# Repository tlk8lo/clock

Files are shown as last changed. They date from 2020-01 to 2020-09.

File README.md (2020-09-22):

# Timer

A school timer which displays time to the end of lesson/break. Uses [DCF77](https://en.wikipedia.org/wiki/DCF77) time signal for synchronization. Can also work as a typical digital clock. Since this is a project for our school, the documentation is written in Polish.

Szkolny timer wyświetlający czas do końca lekcji/przerwy. Używa sygnału radiowego [DCF77](https://en.wikipedia.org/wiki/DCF77) do synchronizacji czasu. Może również pracować jako normalny zegar cyfrowy.

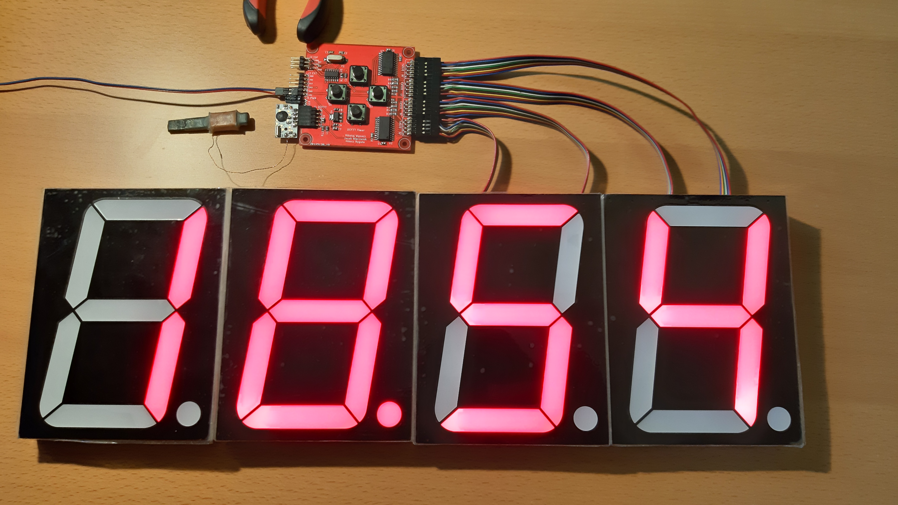
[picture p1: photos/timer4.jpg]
Timer


## Budowa

Urządzenie składa się z mikrokontrolera AVR ATtiny24A, modułu odbiornika sygnału DCF77 oraz 2 układów SCT2024 sterujących 4 dużymi wyświetlaczami 7-segmentowymi. Posiada 4 przyciski do konfiguracji godzin lekcyjnych (zapisywanych w pamięci EEPROM). Wymaga zasilania prądem stałym o napięciu **15V** i pobiera maksymalnie **1,2A**. _Podczas montażu urządzenia, przewód zasilający należy poprowadzić jak najdalej od anteny, ponieważ powoduje on znaczne zakłócenia._

## Sposób działania

Po włączeniu zasilania, urządzenie czeka na odebranie poprawnej ramki DCF77 w celu synchronizacji czasu. Po udanej synchronizacji, wyświetla:

* Aktualną godzinę (jeżeli nie są zapisane żadne lekcje)
* Czas do końca przerwy (jeżeli trwa przerwa)
* Czas do końca lekcji (jeżeli trwa lekcja) - zapala się wtedy kropka po prawej stronie 4 cyfry

Kropka pomiędzy 2 i 3 cyfrą informuje o statusie synchronizacji:

* Jeżeli odebrano poprawną ramkę DCF77 w ciągu ostatnich 24 godzin - kropka świeci się
* W przeciwnym razie - kropka odzwierciedla stan odbiornika DCF77 (pozwala to wizualnie ocenić jakość odbieranego sygnału)

## Konfiguracja lekcji

W celu konfiguracji godzin lekcyjnych, należy nacisnąć dowolny przycisk, aby wejść do menu głównego.\
W menu, poszczególne przyciski umożliwiają nawigację, na zasadzie strzałek:

```
  ↑  
←   →
  ↓  
```

**Menu główne**

W menu głównym można ustawić godziny rozpoczęcia i zakończenia poszczególnych lekcji, a także dodawać i usuwać lekcje.\
Można dodać maksymalnie 32 lekcje.\
Jeżeli usunie się wszystkie lekcje, urządzenie działa jak zwyczajny zegar.

_Na poniższym przykładzie dodano 9 lekcji (od 00 do 08)._

```
                  ------------ Ustaw początek lekcji ------------         Dodaj nową lekcję          
                  ↑                 ↑                           ↑                 ↑                  
             ┌─────────┐       ┌─────────┐                 ┌─────────┐       ┌─────────┐             
Wyjdź    ←   │ 0 0   L │   ↔   │ 0 1   L │   ↔   ...   ↔   │ 0 8   L │   ↔   │ L A S T │   →   Wyjdź 
z menu       └─────────┘       └─────────┘                 └─────────┘       └─────────┘       z menu
                  ↓                 ↓                           ↓                 ↓                  
                  ------------- Ustaw koniec lekcji -------------        Usuń ostatnią lekcję        
```

**Menu ustawiania początku/końca lekcji**

To menu umożliwia zmianę godziny początku/końca danej lekcji.\
Kropka oznacza aktualnie edytowaną cyfrę.\
Domyślnie lekcja trwa 45 min, dlatego koniec lekcji jest ustawiany automatycznie. (Koniec lekcji można nadpisać ręcznie, wybierając "Ustaw koniec lekcji" w menu głównym.)

_Na poniższym przykładzie ustawiono godzinę 09:45._

```
               +                   +                   +                   +               
               ↑                   ↑                   ↑                   ↑               
             ┌─────────┐       ┌─────────┐       ┌─────────┐       ┌─────────┐             
Wróć do  ←   │ 0.9 4 5 │   ↔   │ 0 9.4 5 │   ↔   │ 0 9 4.5 │   ↔   │ 0 9 4 5.│   →  Wróć do
menu gł      └─────────┘       └─────────┘       └─────────┘       └─────────┘      menu gł
               ↓                   ↓                   ↓                   ↓               
               -                   -                   -                   -               
```

## Struktura repozytorium

* [src](src) - kod źródłowy programu mikrokontrolera
* [pcb](pcb) - schemat obwodu i projekt płytki PCB
* [cad](cad) - modele elementów obudowy
* [photos](photos) - zdjęcia gotowego urządzenia

## Licencja

[MIT](LICENSE)

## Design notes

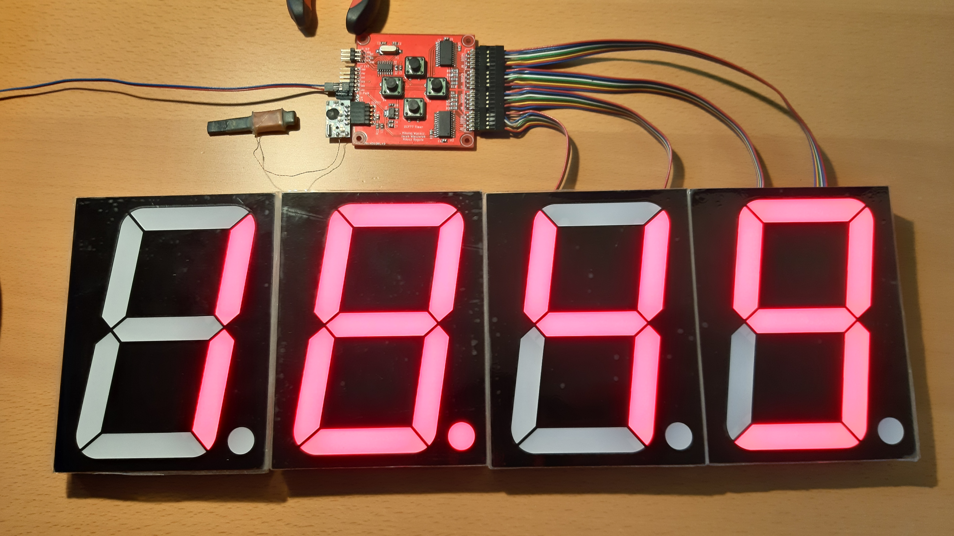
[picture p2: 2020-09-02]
photos/timer3.jpg

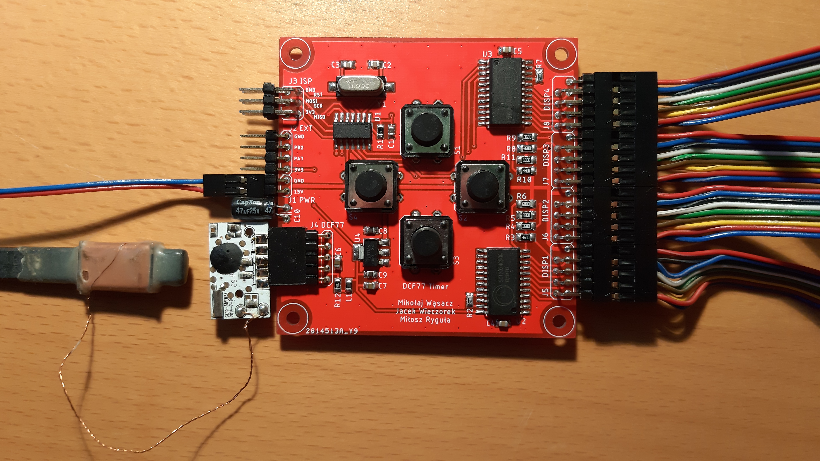
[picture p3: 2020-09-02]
photos/timer1.jpg

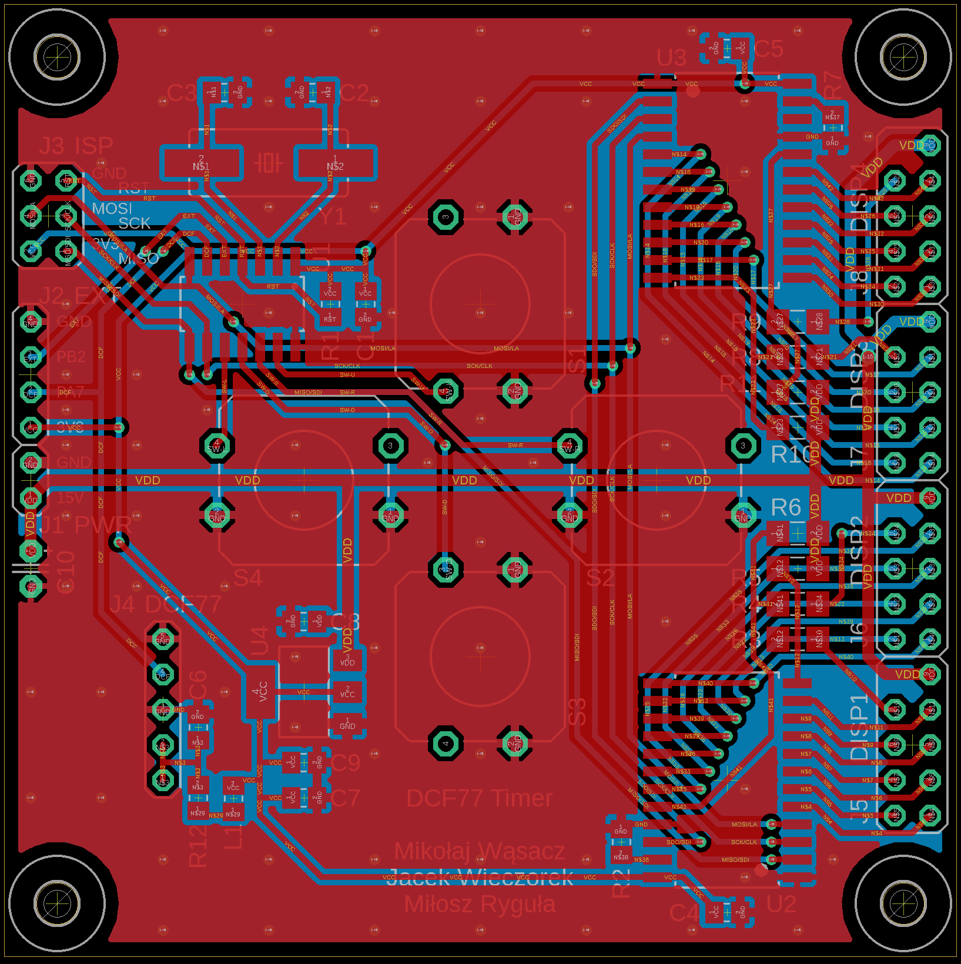
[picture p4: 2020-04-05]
pcb/Timer.brd.png

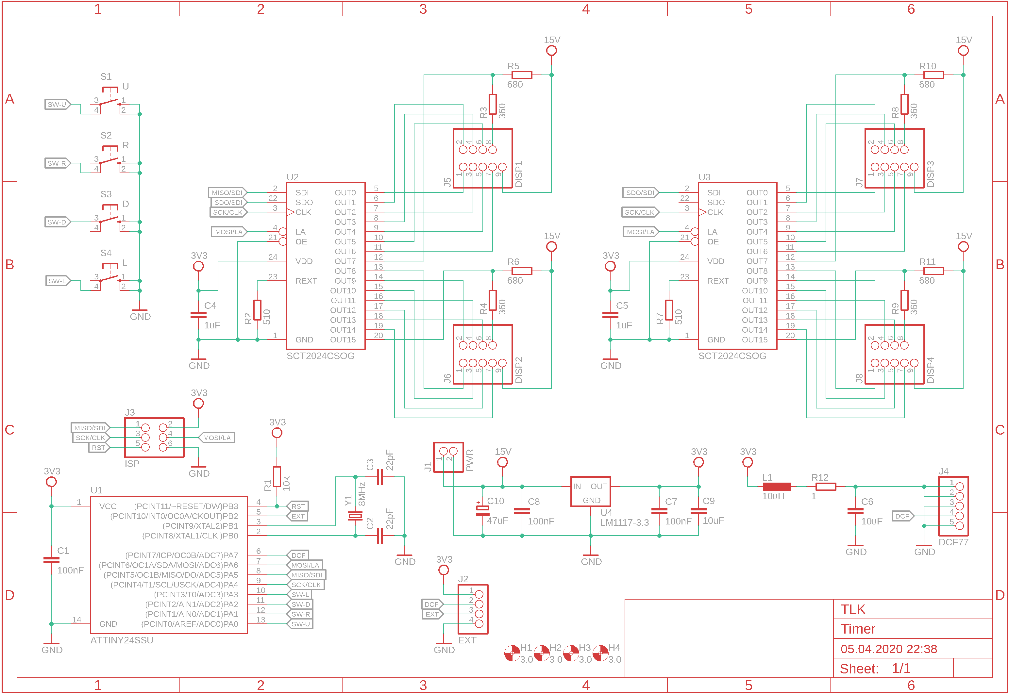
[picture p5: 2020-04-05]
pcb/Timer.sch.png

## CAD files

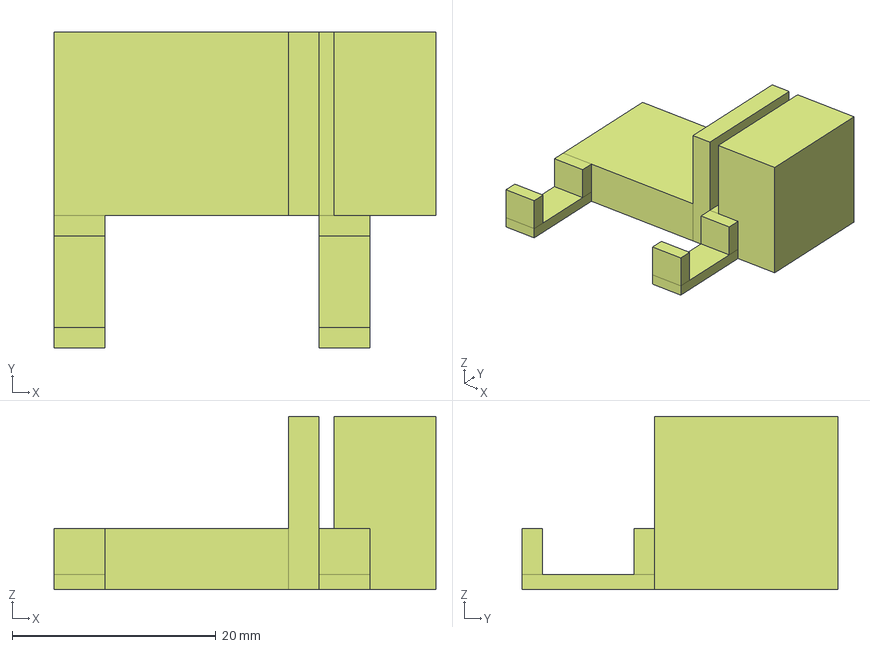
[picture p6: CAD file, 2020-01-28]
cad/dystans.fcstd
37.5 x 31.0 x 17.0 mm

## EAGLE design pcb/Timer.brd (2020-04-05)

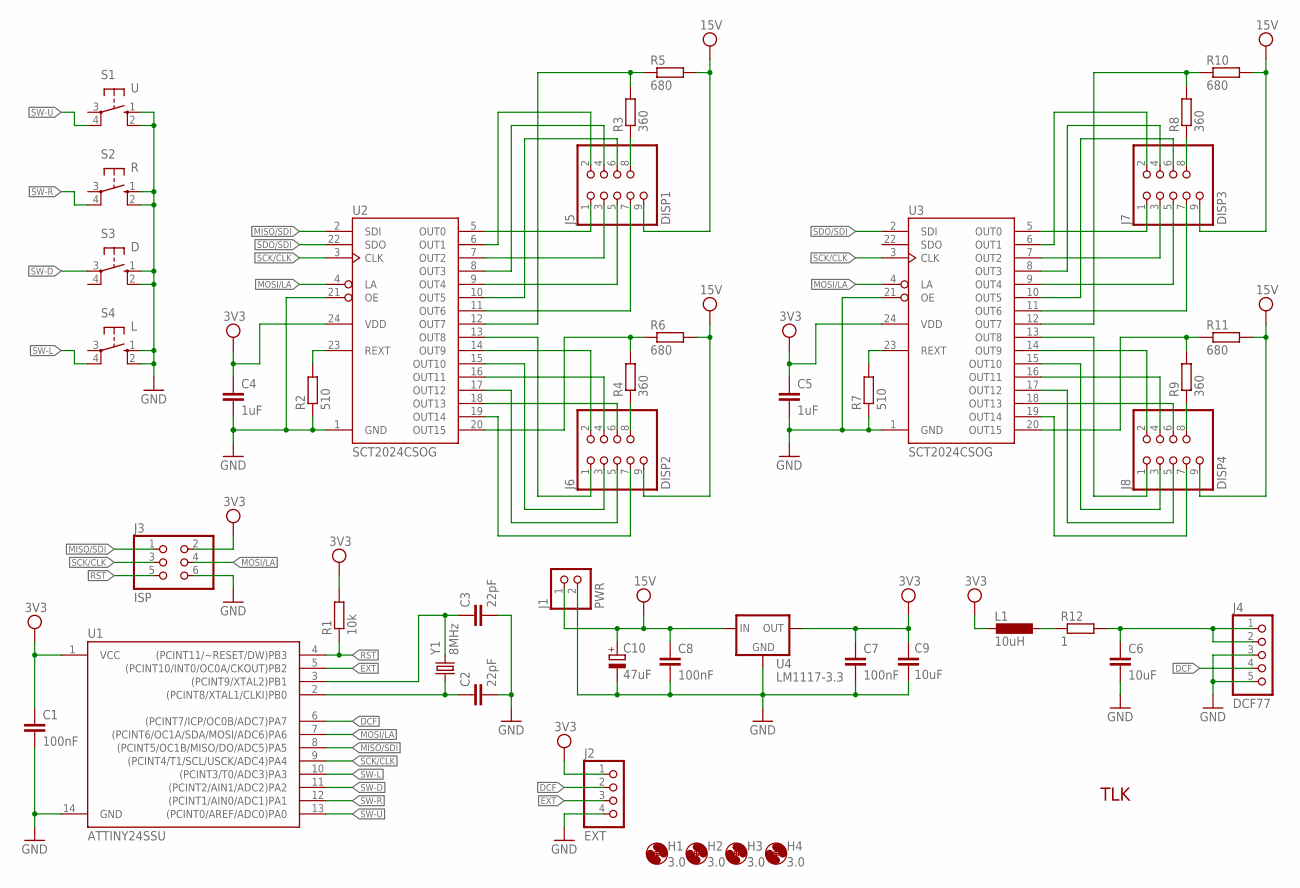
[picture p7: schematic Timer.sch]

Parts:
C1, C7, C8: 100nF; C0805
C2, C3: 22pF; C0805
C4, C5: 1uF; C0805
C6, C9: 10uF; C0805
C10: 47uF; E2,5
H1, H2, H3, H4: 3.0; 3,0
J1: PWR; 1X02/90
J2: EXT; 1X04/90
J3: ISP; 2X03/90
J4: DCF77; 1X05/90
J5: DISP1; 2X04/05/90
J6: DISP2; 2X04/05/90
J7: DISP3; 2X04/05/90
J8: DISP4; 2X04/05/90
L1: 10uH; L0805
R1: 10k; R0805
R2, R7: 510; R0805
R3, R4, R8, R9: 360; R1206
R5, R6, R10, R11: 680; R1206
R12: 1; R0805
S1: U; TACT-12
S2: R; TACT-12
S3: D; TACT-12
S4: L; TACT-12
U1: ATTINY24SSU; SO14
U2, U3: SCT2024CSOG; SO24W
U4: LM1117-3.3; SOT223
Y1: 8MHz; HC49UP

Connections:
DCF: J2.2, J4.4, U1.6 ((PCINT7/ICP/OC0B/ADC7)PA7)
EXT: J2.3, U1.5 ((PCINT10/INT0/OC0A/CKOUT)PB2)
GND: C1.2, C2.2, C3.2, C4.2, C5.2, C6.2, C7.2, C8.2, C9.2, C10.-, J1.2, J2.4, J3.6, J4.3, J4.5, R2.1, R7.1, S1.1 (S), S1.2 (S1), S2.1 (S), S2.2 (S1), S3.1 (S), S3.2 (S1), S4.1 (S), S4.2 (S1), U1.14 (GND), U2.1 (GND), U2.21 (OE), U3.1 (GND), U3.21 (OE), U4.1 (GND)
MISO/SDI: J3.1, U1.8 ((PCINT5/OC1B/MISO/DO/ADC5)PA5), U2.2 (SDI)
MOSI/LA: J3.4, U1.7 ((PCINT6/OC1A/SDA/MOSI/ADC6)PA6), U2.4 (LA), U3.4 (LA)
unnamed: C3.1, U1.3 ((PCINT9/XTAL2)PB1), Y1.2
unnamed: C2.1, U1.2 ((PCINT8/XTAL1/CLKI)PB0), Y1.1
unnamed: C6.1, J4.1, J4.2, R12.2
unnamed: J5.1, U2.5 (OUT0)
unnamed: J5.2, U2.6 (OUT1)
unnamed: J5.3, U2.7 (OUT2)
unnamed: J5.4, U2.8 (OUT3)
unnamed: J5.5, U2.9 (OUT4)
unnamed: J5.6, U2.10 (OUT5)
unnamed: J5.8, R3.1
unnamed: J5.7, U2.11 (OUT6)
unnamed: R3.2, R5.1, U2.12 (OUT7)
unnamed: J6.2, U2.14 (OUT9)
unnamed: J7.1, U3.5 (OUT0)
unnamed: J7.3, U3.7 (OUT2)
unnamed: J7.5, U3.9 (OUT4)
unnamed: J7.7, U3.11 (OUT6)
unnamed: J7.2, U3.6 (OUT1)
unnamed: J7.4, U3.8 (OUT3)
unnamed: J7.6, U3.10 (OUT5)
unnamed: J7.8, R8.1
unnamed: J6.4, U2.16 (OUT11)
unnamed: R8.2, R10.1, U3.12 (OUT7)
unnamed: J8.2, U3.14 (OUT9)
unnamed: J8.4, U3.16 (OUT11)
unnamed: J8.6, U3.18 (OUT13)
unnamed: R9.2, R11.1, U3.20 (OUT15)
unnamed: J8.8, R9.1
unnamed: L1.1, R12.1
unnamed: J8.1, U3.13 (OUT8)
unnamed: J8.3, U3.15 (OUT10)
unnamed: J8.5, U3.17 (OUT12)
unnamed: J6.6, U2.18 (OUT13)
unnamed: J6.8, R4.1
unnamed: J6.7, U2.19 (OUT14)
unnamed: J6.5, U2.17 (OUT12)
unnamed: R7.2, U3.23 (REXT)
unnamed: R2.2, U2.23 (REXT)
unnamed: J6.3, U2.15 (OUT10)
unnamed: J6.1, U2.13 (OUT8)
unnamed: R4.2, R6.1, U2.20 (OUT15)
unnamed: J8.7, U3.19 (OUT14)
RST: J3.5, R1.1, U1.4 ((PCINT11/~RESET/DW)PB3)
SCK/CLK: J3.3, U1.9 ((PCINT4/T1/SCL/USCK/ADC4)PA4), U2.3 (CLK), U3.3 (CLK)
SDO/SDI: U2.22 (SDO), U3.2 (SDI)
SW-D: S3.3, U1.11 ((PCINT2/AIN1/ADC2)PA2)
SW-L: S4.4 (P1), U1.10 ((PCINT3/T0/ADC3)PA3)
SW-R: S2.4 (P1), U1.12 ((PCINT1/AIN0/ADC1)PA1)
SW-U: S1.4 (P1), U1.13 ((PCINT0/AREF/ADC0)PA0)
VCC: C1.1, C4.1, C5.1, C7.1, C9.1, J2.1, J3.2, L1.2, R1.2, U1.1 (VCC), U2.24 (VDD), U3.24 (VDD), U4.2 (OUT), U4.4 (OUT)
VDD: C8.1, C10.+, J1.1, J5.9, J6.9, J7.9, J8.9, R5.2, R6.2, R10.2, R11.2, U4.3 (IN)

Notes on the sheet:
TLK

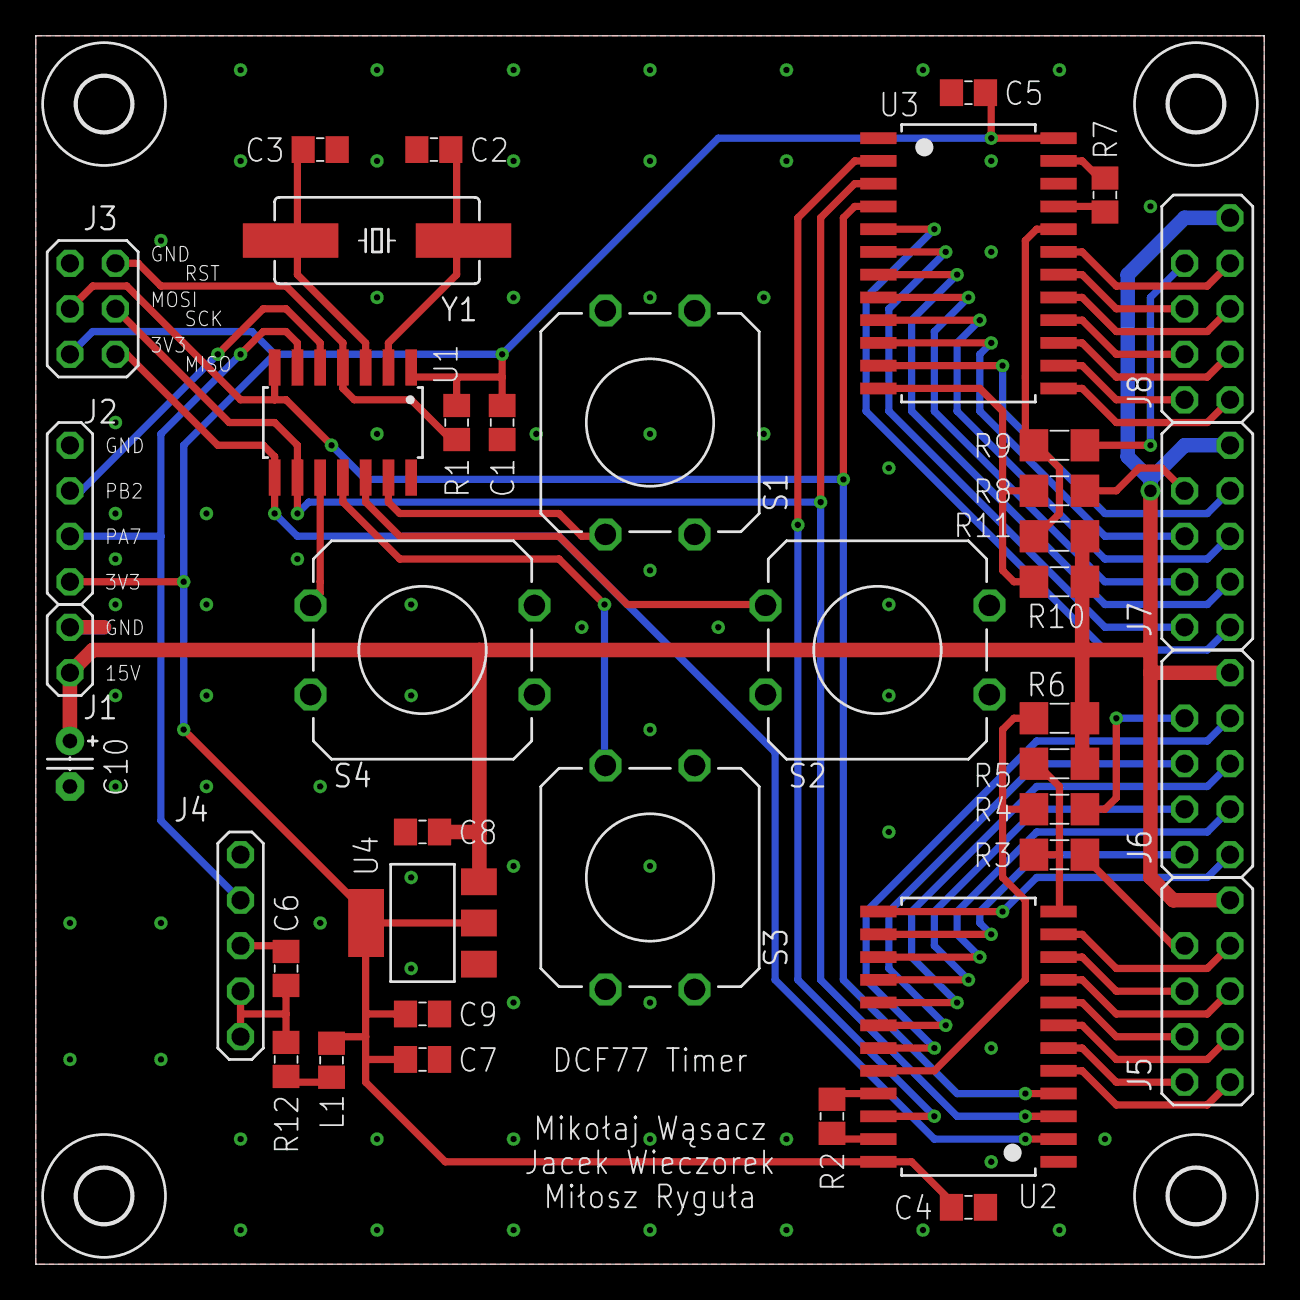
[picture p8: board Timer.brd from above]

Board: 2 copper layers, 68.6 x 68.6 mm, 44 parts (0 on the bottom side), 56 nets.

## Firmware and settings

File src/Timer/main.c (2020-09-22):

/*
	A school timer which displays time to the end of lesson/break.
	
	Microcontroller: AVR ATtiny24A
	Fuse bits: Low:0xFF High:0xD5 Ext:0xFF
	Clock: 8 MHz Crystal
*/

#include <avr/io.h>
#include <avr/interrupt.h>
#include "dcf.h"
#include "display.h"
#include "menu.h"

/*
	Ports configuration
*/
#define DCF_DDR		DDRA
#define DCF_PORT	PORTA
#define DCF_PIN		PINA
#define DCF_BIT		7

#define BTN_DDR		DDRA
#define BTN_PORT	PORTA
#define BTN_PIN		PINA
#define BTN_MASK	15
#define BTN_U		0
#define BTN_R		1
#define BTN_D		2
#define BTN_L		3

#define DISP_DDR	DDRA
#define DISP_PORT	PORTA
#define DISP_PIN	PINA
#define DISP_CLK	4
#define DISP_DATA	5
#define DISP_LOAD	6

/*
	Timer1 comp interrupt period consts

	Interrupt period = 1 s * F_CPU / Prescaler
	Interrupt period = 1 * 8000000 / 256
	Interrupt period = 31250
*/
#define SEC_OCR_VAL	31250
#define SEC_RES_VAL	6250
#define BTN_DEB_VAL	312

/*
	Timer0 comp interrupt period consts

	Interrupt period = 20 ms * F_CPU / Prescaler
	Interrupt period = 0.02 * 8000000 / 1024
	Interrupt period = 156
*/
#define DCF_OCR_VAL	156

/*
	DCF waveform

	Time:          0        100       200       300       400       500       600       700       800       900       1000
	               ---------------------                                                                               ------
	               |         |         |                                                                               |
	Waveform:      |   "0"   |   "1"   |                                                                               |
	               |         |         |                                                                               |
	           -----         -------------------------------------------------------------------------------------------
	               ^    ^         ^         ^                                                                     ^         ^
	Threshold:   Reset  1         2         3                                                                     4         5
*/

/*
	DCF time consts (in units of 20 ms)
	1 - 40 ms
	2 - 140 ms
	3 - 240 ms
	4 - 900 ms
	5 - 1100 ms
	OVF - 1800 ms
	RES - 200 ms
*/
#define DCF_1_THRES	2
#define DCF_2_THRES	7
#define DCF_3_THRES	12
#define DCF_4_THRES	45
#define DCF_5_THRES	55
#define DCF_OVF_VAL	90
#define DCF_RES_VAL	10

#define UPDATE_DISP	0
#define DCF_SYNC	1
//static volatile uint8_t flags;
#define flags		GPIOR0

//static volatile uint8_t ms_dcf;
#define ms_dcf		GPIOR1
static uint8_t data[59];

static volatile uint24_t seconds;
static volatile uint24_t last_sync;
//static volatile uint8_t sync_dot;
#define sync_dot	GPIOR2

struct dcf
{
	uint8_t state;
	uint8_t cnt;
};

#define load_display() do { DISP_PORT |= (1<<DISP_LOAD); DISP_PORT &= ~(1<<DISP_LOAD); } while (0)

static void check_dcf(struct dcf *dcf)
{
	cli();
	uint8_t tim = ms_dcf;

	// DCF timer overflow
	if (tim == DCF_OVF_VAL)
	{
		sei();
		if (dcf->cnt == 59 && !dcf->state && dcf_validate(data))
		{
			uint24_t s = dcf_parse(data);
			
			cli();
			GTCCR = (1<<PSR10);
			uint16_t tcnt = TCNT1;
			if (tcnt >= SEC_OCR_VAL - (SEC_RES_VAL - 1))
				OCR1A = tcnt + (SEC_RES_VAL - 1) - SEC_OCR_VAL;
			else
				OCR1A = tcnt + (SEC_RES_VAL - 1);
			TIFR1 = (1<<OCF1A);
			TIMSK1 |= (1<<OCIE1A);

			last_sync = s;
			flags |= (1<<DCF_SYNC);
		}

		dcf->cnt = 0;
	}
	
	uint8_t new_state = DCF_PIN & (1<<DCF_BIT);
	sei();

	// DCF edge interrupt
	if (new_state != dcf->state)
	{
		// Rising edge
		if (new_state)
		{
			cli();
			TCNT0 = 0;
			TIFR0 = (1<<OCF0A);
			ms_dcf = 0;
			sei();

			if ((dcf->cnt && dcf->cnt < 59 && tim >= DCF_4_THRES && tim < DCF_5_THRES) || tim == DCF_OVF_VAL)
				dcf->cnt++;
			else
				dcf->cnt = 0;
		}
		// Falling edge
		else
		{
			if (dcf->cnt && tim >= DCF_1_THRES && tim < DCF_3_THRES)
				data[dcf->cnt - 1] = tim >= DCF_2_THRES;
			else
			{
				cli();
				TCNT0 = 0;
				TIFR0 = (1<<OCF0A);
				ms_dcf = DCF_RES_VAL;
				sei();
				
				dcf->cnt = 0;
			}
		}
		
		dcf->state = new_state;
		if (!(sync_dot & CHAR_DOT))
			flags |= (1<<UPDATE_DISP);
	}
}

static void check_pin_change()
{
	cli();
	if (GIFR & (1<<PCIF0))
	{
		GIFR = (1<<PCIF0);
		uint16_t tcnt = TCNT1;
		if (tcnt >= SEC_OCR_VAL - (BTN_DEB_VAL - 1))
			OCR1B = tcnt + (BTN_DEB_VAL - 1) - SEC_OCR_VAL;
		else
			OCR1B = tcnt + (BTN_DEB_VAL - 1);
		TIFR1 = (1<<OCF1B);
	}
	sei();
}

/*
	Increment DCF timer until it reaches DCF_OVF_VAL
*/
ISR(TIM0_COMPA_vect)
{
	uint8_t dcf = ms_dcf;
	if (dcf < DCF_OVF_VAL)
		ms_dcf = dcf + 1;
}

/*
	Increment seconds counter
*/
ISR(TIM1_COMPA_vect)
{
	uint24_t s = seconds + 1;
	if (s >= (uint24_t)24 * 60 * 60)
		s = 0;

	uint24_t l = last_sync;
	if (flags & (1<<DCF_SYNC))
	{
		flags &= ~(1<<DCF_SYNC);
		sync_dot |= CHAR_DOT;
		s = l;
	}
	else if (s == l)
		sync_dot &= ~CHAR_DOT;
	
	seconds = s;
	flags |= (1<<UPDATE_DISP);
}

int main(void)
{
	// Setup ports
	DDRA = (1<<DISP_CLK) | (1<<DISP_DATA) | (1<<DISP_LOAD);
	PORTA = (1<<BTN_U) | (1<<BTN_R) | (1<<BTN_D) | (1<<BTN_L) | (1<<DCF_BIT);
	
	// Turn off ADC
	PRR |= (1<<PRADC);

	// Pin Change Interrupt config
	PCMSK0 = (1<<PCINT0) | (1<<PCINT1) | (1<<PCINT2) | (1<<PCINT3);
	
	// USI config
	USICR = (1<<USIWM0) | (1<<USICS1) | (1<<USICLK);

	// Timer 0 config - CTC, prescaler = 1024
	OCR0A = DCF_OCR_VAL - 1;
	TCCR0A = (1<<WGM01);
	TCCR0B = (1<<CS02) | (1<<CS00);
	TIMSK0 = (1<<OCIE0A);

	// Timer 1 config - CTC, prescaler = 256
	ICR1 = SEC_OCR_VAL - 1;
	TCCR1B = (1<<WGM13) | (1<<WGM12) | (1<<CS12);

	flags |= (1<<UPDATE_DISP);

	uint8_t old = BTN_PIN;
	struct dcf dcf = { old & (1<<DCF_BIT) };

	// Main loop
	while (1)
	{
		sei();
		struct menu menu = { 0 };

		do
		{
			check_dcf(&dcf);
			check_pin_change();

			if (TIFR1 & (1<<OCF1B))
			{
				uint8_t new = BTN_PIN;
				uint8_t btn = old & ~new;
				old = new;

				if (btn & BTN_MASK)
				{
					if (menu.page == NONE)
					{
						menu.page = MAIN;
						flags |= (1<<UPDATE_DISP);
					}
					else if (btn & (1<<BTN_U))
						btn_up(&menu);
					else if (btn & (1<<BTN_R))
						btn_right(&menu);
					else if (btn & (1<<BTN_D))
						btn_down(&menu);
					else if (btn & (1<<BTN_L))
						btn_left(&menu);

					if (menu.page != NONE)
					{
						display_menu(&menu);
						load_display();
					}
				}
			}
		} while (menu.page != NONE);
		
		cli();
		if (flags & (1<<UPDATE_DISP))
		{
			flags &= ~(1<<UPDATE_DISP);
			uint24_t sec = seconds;
			uint8_t sync = sync_dot;
			sei();

			display_time(sec, sync | dcf.state);
			load_display();
		}
	}
}

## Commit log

2019-10-16 Add BOM
2019-11-11 Add schematic and preliminary pcb layout
    [Timer.brd, Timer.sch]
2019-12-01 Add Extension connector, move some traces
    [Timer.brd, Timer.sch]
2019-12-02 Add ground planes
    [Timer.brd]
2019-12-17 Add CAD models
    [dystans.fcstd]
2020-01-28 Update 'dystans'
    [dystans.fcstd]
2020-03-08 Update footprints and silkscreen
    [Timer.brd, Timer.sch]
2020-04-05 Fix errors, move components to a common library
    [Timer.brd, Timer.sch]
2020-04-05 Change C6 value
    [Timer.brd, Timer.sch]
2020-04-05 Add Gerber files
2020-06-28 Add missing `static` specifier
    See: https://stackoverflow.com/questions/16245521/c99-inline-function-in-c-file/16245669#16245669
    [main.c]
2020-06-29 Add more missing static specifiers
    [main.c]
2020-09-14 Change device to ATtiny24A
2020-09-17 Fix bugs, add option to set current time
    [main.c]
2020-09-21 Revert "Fix bugs, add option to set current time"
    This reverts commit 75b06e3f8055a057145ca035266ad130e721dde4.
    [main.c]
2020-09-22 Add DCF signal indicator, fix minor bugs
    [main.c]
